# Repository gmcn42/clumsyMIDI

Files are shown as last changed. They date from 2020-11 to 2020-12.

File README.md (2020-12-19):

# clumsyMIDI
A Raspberry Pi expansion board containing a MIDI interface, DAC, and OLED display requiring only through-hole soldering skills. This is primarily intended as an all-in-one hardware solution for the [mt32-pi Roland MT-32 emulator](https://github.com/dwhinham/mt32-pi) but all features are usable with Raspberry Pi OS, too.

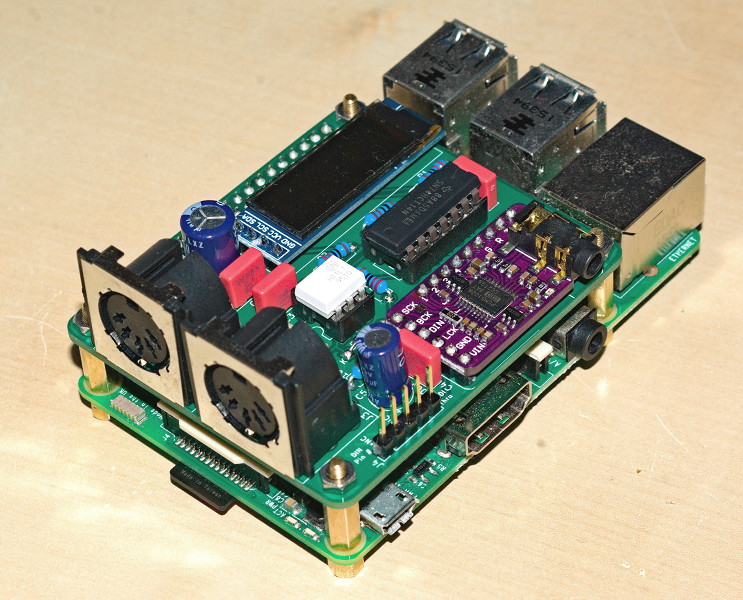
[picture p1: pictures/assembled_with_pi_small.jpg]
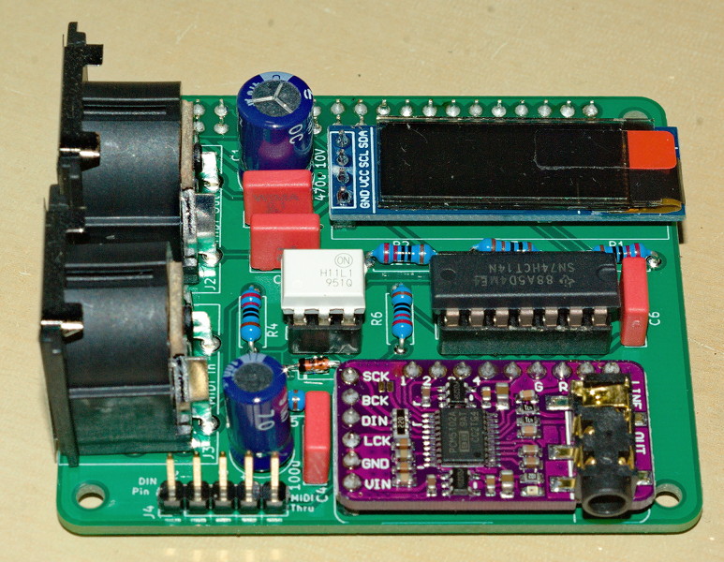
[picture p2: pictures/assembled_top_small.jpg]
[](https://github.com/gmcn42/clumsyMIDI/raw/main/pictures/assembled_with_pi.jpg) [](https://github.com/gmcn42/clumsyMIDI/raw/main/pictures/assembled_top.jpg)

## Table of contents

<!-- toc -->
- [Features](#features)
- [Schematic and BOM](#schematic-and-bom)
- [How to get the PCB](#how-to-get-the-pcb)
  * [PCB Specs](#pcb-specs)
- [Assembly](#assembly)
  * [An ⚠IMPORTANT⚠ note on the DAC board solder bridges](#an-important-note-on-the-dac-board-solder-bridges)
  * [Rewiring MIDI Thru to Out](#rewiring-midi-thru-to-out)
  * [Mechanical Parts](#mechanical-parts)
  * [A General Note](#a-general-note)
- [Software Config](#software-config)
  * [mt32-pi](#mt32-pi)
  * [Raspberry Pi OS](#raspberry-pi-os)

<!-- tocstop -->

## Features
* TI PCM5102 I2S HiFi DAC (using the ubiquitous GY-PCM5102 carrier board)
* GPIO MIDI interface with in, out, and thru
* 0.91" OLED display
* large-ish 5V bypass capacitor which may help with slightly weak power supplies
* works with [mt32-pi](https://github.com/dwhinham/mt32-pi) and Raspberry Pi OS
* no SMT soldering required, so it should be suitable for clumsy DIYers like me ;)

## Schematic and BOM
Schematic and BOM are available in the [`pdf/` subfolder](https://github.com/gmcn42/clumsyMIDI/tree/main/pdf).

## How to get the PCB
You can get a zip file with the Gerber files from the [releases page](https://github.com/gmcn42/clumsyMIDI/releases/) and let your favorite board house build the PCB. Alternatively, you can also order directly from PCBWAY via [this link](https://www.pcbway.com/project/shareproject/clumsyMIDI___Raspberry_Pi_expansion_board.html) for convenience. Full disclosure: If you use the link, PCBWAY will donate 10% of the PCB price to me. I want to make clear that the PCB design is completely free and you are in no way obligated or even encouraged to use that link.

In case you want to make changes to the PCB before ordering somewhere, you can use [KiCAD](https://kicad.org/) and import the project.

***⚠IMPORTANT NOTE:⚠*** Before soldering down the DAC board please make *sure* you check the [assembly instructions below about the DAC's solder bridges](#an-important-note-on-the-dac-board-solder-bridges). Their factory configuration appears to be varying from supplier to supplier and you may need to change them.

### PCB Specs
* PCB size (height * width): 56mm * 65mm
* Layers: 2
* Minimum drill size: 0.6mm
* Minimum track size: 0.25mm (=9.84mil)
* Minimum track clearance/spacing: 0.25mm (=9.84mil)
* Surface finish: by preference (the pictured boards are lead-free HASL but pretty much anything will do)

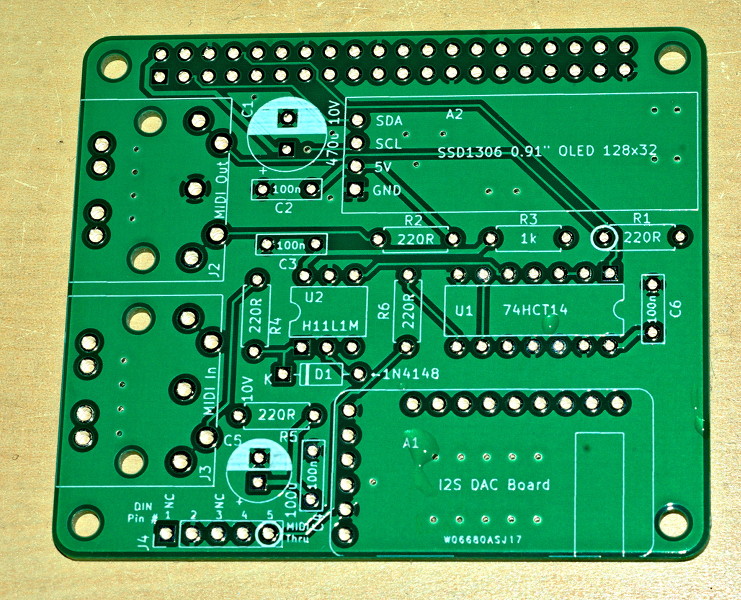
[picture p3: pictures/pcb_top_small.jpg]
[](https://github.com/gmcn42/clumsyMIDI/raw/main/pictures/pcb_top.jpg)
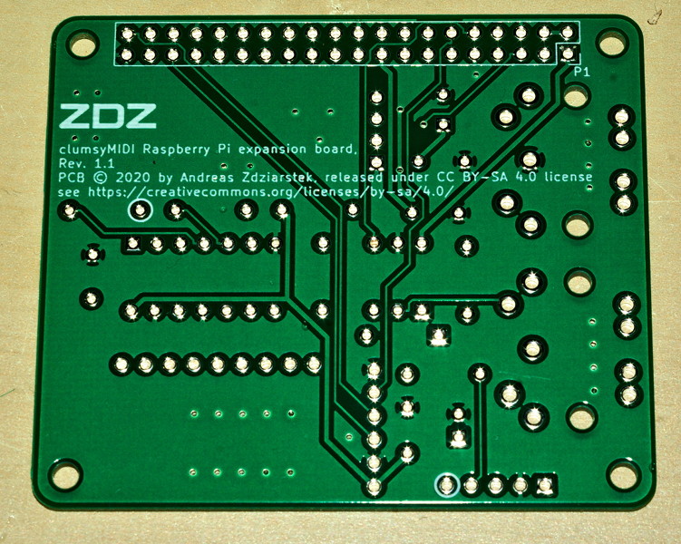
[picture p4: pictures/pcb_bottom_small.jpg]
[](https://github.com/gmcn42/clumsyMIDI/raw/main/pictures/pcb_bottom.jpg)

## Assembly
As all components are through-hole, you should get by with basic soldering skills. It is usually the best idea to start with the flattest components and work your way up. The 40-Pin GPIO socket should be soldered on last, also remember that it goes on the *bottom* :).

As shown in the BOM, I recommend socketing U1 and U2 as they are the most likely casualties if defective MIDI devices are connected for some reason. Be mindful of the ICs' orientation. The notch of the 74HCT14 should be where the notch is on the silkscreen. Likewise, the H11L1's dot (marking for Pin 1) should also face the in the direction of the notch on the silkscreen. If inserted correctly, U1 and U2 will "face outward and away from each other".

It is possible to leave out some components, e.g. if you only need MIDI-In. Consult [the schematic](https://github.com/gmcn42/clumsyMIDI/blob/main/pdf/clumsyMIDI-schematic.pdf) for details.

As I happily noticed people are actually really starting to build these things, I have opened the [discussions page](https://github.com/gmcn42/clumsyMIDI/discussions) of this project. If you have questions about anything related to the board and its assembly, feel free to open a topic!

### An ⚠IMPORTANT⚠ note on the DAC board solder bridges
Before soldering on the DAC board please double-check that the solder bridges on the bottom of your GY-PCM5102 are configured as in the following picture:

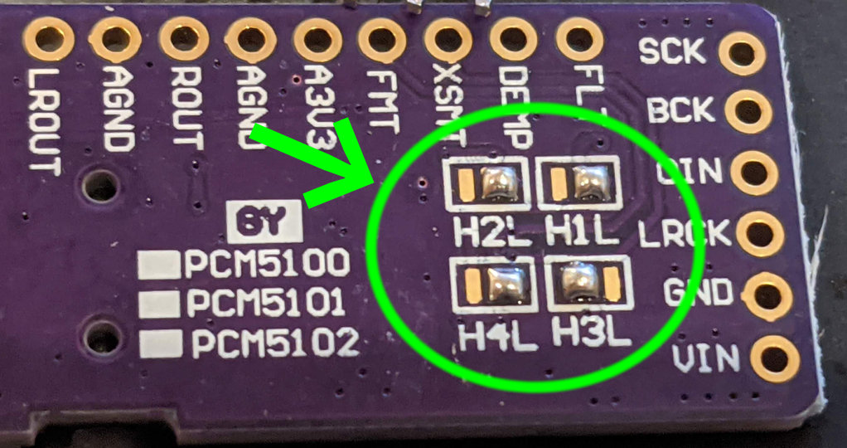
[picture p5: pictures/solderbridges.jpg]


So: 1, 2, and 4 to L and 3 to H. This should be the standard factory-set config but at least one builder encountered a board with an unconnected bridge resulting in the DAC being permanently muted. If you have a multimeter you might also want to check good connection from the board's pins to rule out bad solder joints. FLT, FMT, and DEMP should have almost 0Ω to GND while XSMT should have almost 0Ω to pin 20 (top right) of the DAC chip itself.

If yours are un- or wrongly set, you'll have to resolder them.

### Rewiring MIDI Thru to Out
In standard configuration, the MIDI Thru output is available on a 5-pin header due to space constraints. If you do not need MIDI Out but want a MIDI Thru, it is possible to route the Thru signal to the MIDI-Out socket instead of the pin header. In that case, leave J4, R1, and R5 unpopulated and solder a wire between the footprint pads of J4 and R1 marked with a circle on the silkscreen, as shown in these two pictures (click for larger version):

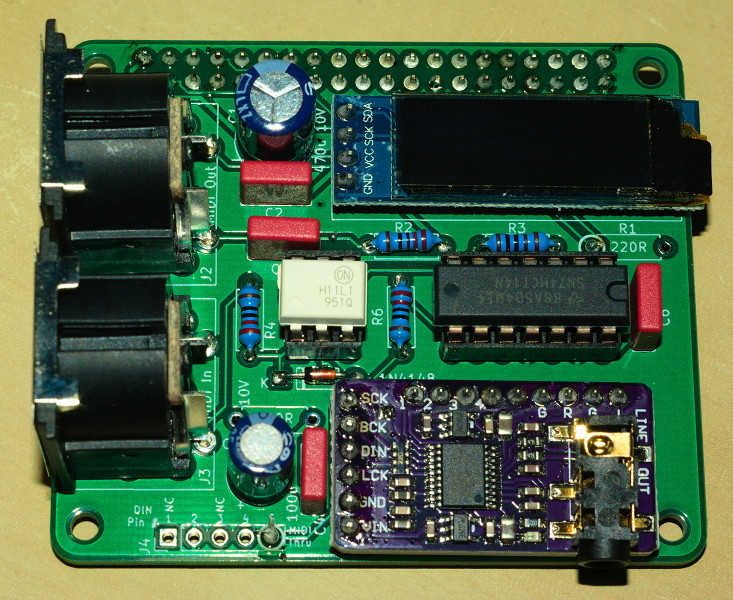
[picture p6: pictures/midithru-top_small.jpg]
[](https://github.com/gmcn42/clumsyMIDI/raw/main/pictures/midithru-top.jpg)
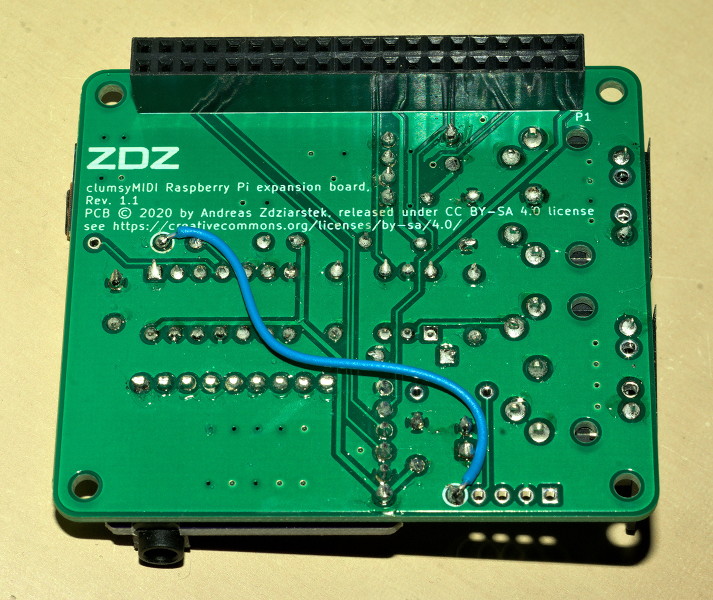
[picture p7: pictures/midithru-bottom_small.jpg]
[](https://github.com/gmcn42/clumsyMIDI/raw/main/pictures/midithru-bottom.jpg)

### Mechanical Parts
Be sure to use some kind of standoffs or similar when connecting clumsyMIDI to the PI. Without them, the board may sit lopsided and come in contact with the HDMI port, potentially causing a short circuit. Apart from that, it's more mechanically stable and simply looks nicer :). The BOM contains the brass standoffs I am using in the pictures.

### A General Note
Use caution and common sense while working with electronics, especially while soldering stuff. As stated in the license, I am offering this PCB design as-is incuding any and all defects it may have and will not be held liable for any harm that comes to you or others as a result of using/building/looking at it.

## Software Config
### mt32-pi
Follow the setup instructions on their site and then set the following options in `mt32-pi.cfg`:
```
usb = off
output_device = i2s
type = ssd1306_i2c
```
The option `gpio_thru` will also work with the MIDI Out port on clumsyMIDI, so use at your preference.

### Raspberry Pi OS
You need to add the following to `/boot/config.txt` to get GPIO MIDI, I2S DAC, and I2C support
```
enable_uart=1
dtoverlay=pi3-miniuart-bt
dtoverlay=midi-uart0

dtparam=i2s=on
dtoverlay=hifiberry-dac

dtparam=i2c_arm=on,i2c_arm_baudrate=400000
```
Also you need to comment out or remove the line `dtparam=audio=on`

Additionally for I2C support, add the following line to `/etc/modules`:
```
i2c-dev
```

To get regular ALSA MIDI support you need to bridge `/dev/ttyAMA0` and an ALSA MIDI port. You can do this with [`ttymidi`](https://github.com/cjbarnes18/ttymidi).
Once you have it compiled and installed, run the following in a terminal:
```
sudo ttymidi -s /dev/ttyAMA0 -b 38400
```
If you are asking yourself why it needs to be set to 38400 Baud: The line `dtoverlay=midi-uart0` causes the Pi's UART base clock to be slightly lowered, so that 38400 (a common RS232 baud rate) effectively becomes 31250 Baud which is MIDI-compatible.

Now you when run `aconnect -l` in another terminal, you should see a new MIDI client. Something similar to:
```
client 128: 'ttymidi' [type=user,pid=920]
    0 'MIDI out     '
    1 'MIDI in      '
```
Somewhat confusingly, the out/in naming is reversed because it is from the perspective of `ttymidi`. That means 'MIDI in' is what it receives from another application and then forwards to the UART. So if you want to play something on a synth connected to the clumsyMIDI's output, the correct command will be
```
aplaymidi -p 128:1 somefile.mid
```

The I2C display is supported by the [Adafruit SSD1306 Python library](https://github.com/adafruit/Adafruit_Python_SSD1306.git), among others.

Have fun!

clumsyMIDI ©2020 by Andreas Zdziarstek.<br>This work is licensed under a [Creative Commons Attribution-ShareAlike 4.0 International License](https://creativecommons.org/licenses/by-sa/4.0/).<br>

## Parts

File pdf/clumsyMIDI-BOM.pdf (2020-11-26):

### clumsyMIDI – Bill of Materials

Total Component Count: 23

Reference | Qnty Value | Footprint | Description
A1, | 1 | GY-PCM5102 | Custom | GY-PCM5102 DAC board (cheaply available on eBay/AliExpress)
A2, | 1 | SSD1306 Header | Custom
C1, | 1 | 470u 10V | Electrolytic capacitor, preferably low ESR
C2, C3, C4, C6, | 4 | 100n | Unpolarized bypass capacitors, use either X7R or film (e.g. WIMA MKS2)
C5, | 1 | 100u | | Electrolytic capacitor
D1, | 1 | 1N4148 | DO-35 | Fast Switching Diode
J2, J3, | 2 | MIDI In & Out Jacks | DIN 5 Pin Jack (Universal) | 5-pin DIN socket, (hopefully) with universal footprint for most types
J4, | 1 | MIDI Thru Jack | Pin Header 1x05 2.54mm Pitch | 5-pin DIN connector (Pin Header only)
P1, | 1 | Conn_02x20_Odd_Even | Raspberry PI GPIO Socket
R1, R2, R4, R5, R6, | 5 | 220Ω | | Resistor
R3, | 1 | 1kΩ | Resistor
U1, | 1 | 74HCT14 | DIP-14 W7.62mm | Hex inverter schmitt trigger
U2, | 1 | H11L1M | DIP-6 W7.62mm
S1, | 1 | DIP-14 socket | DIP-14 W7.62mm | Optional socket for U1
S2, | 1 | DIP-6 socket | DIP-6 W7.62mm | Optional socket for U2
Mechanical Parts: | 4x M2.5 nut, 4x M2.5x11+6 standoff, 4x M2.5x5+6 standoff

0.91” SSD1306 OLED board, use 5V compatible boards with 3.3V regulator (usually marked Q1 or U1) on the back of the board (cheaply available on eBay/AliExpress)
THT Electrolytic Cap Radial D8.0mm, 3.5mm pitch
THT Unpolarized Capacitor, Rectangular 7.0mm x 2.0mm, 5.00mm pitch
THT Electrolytic Cap Radial D6.3mm, 2.5mm pitch

Generic connector, double row, 02x20, odd/even pin numbering scheme (row 1 odd numbers, row 2 even numbers)
THT Resistor DIN0207
(L6.3mm x D2.5mm, 7.62mm
pitch)
THT Resistor DIN0207
(L6.3mm x D2.5mm, 7.62mm
pitch)

Schmitt Trigger Output Optocoupler, High Speed, DIP-6, 1.6mA turn on threshold

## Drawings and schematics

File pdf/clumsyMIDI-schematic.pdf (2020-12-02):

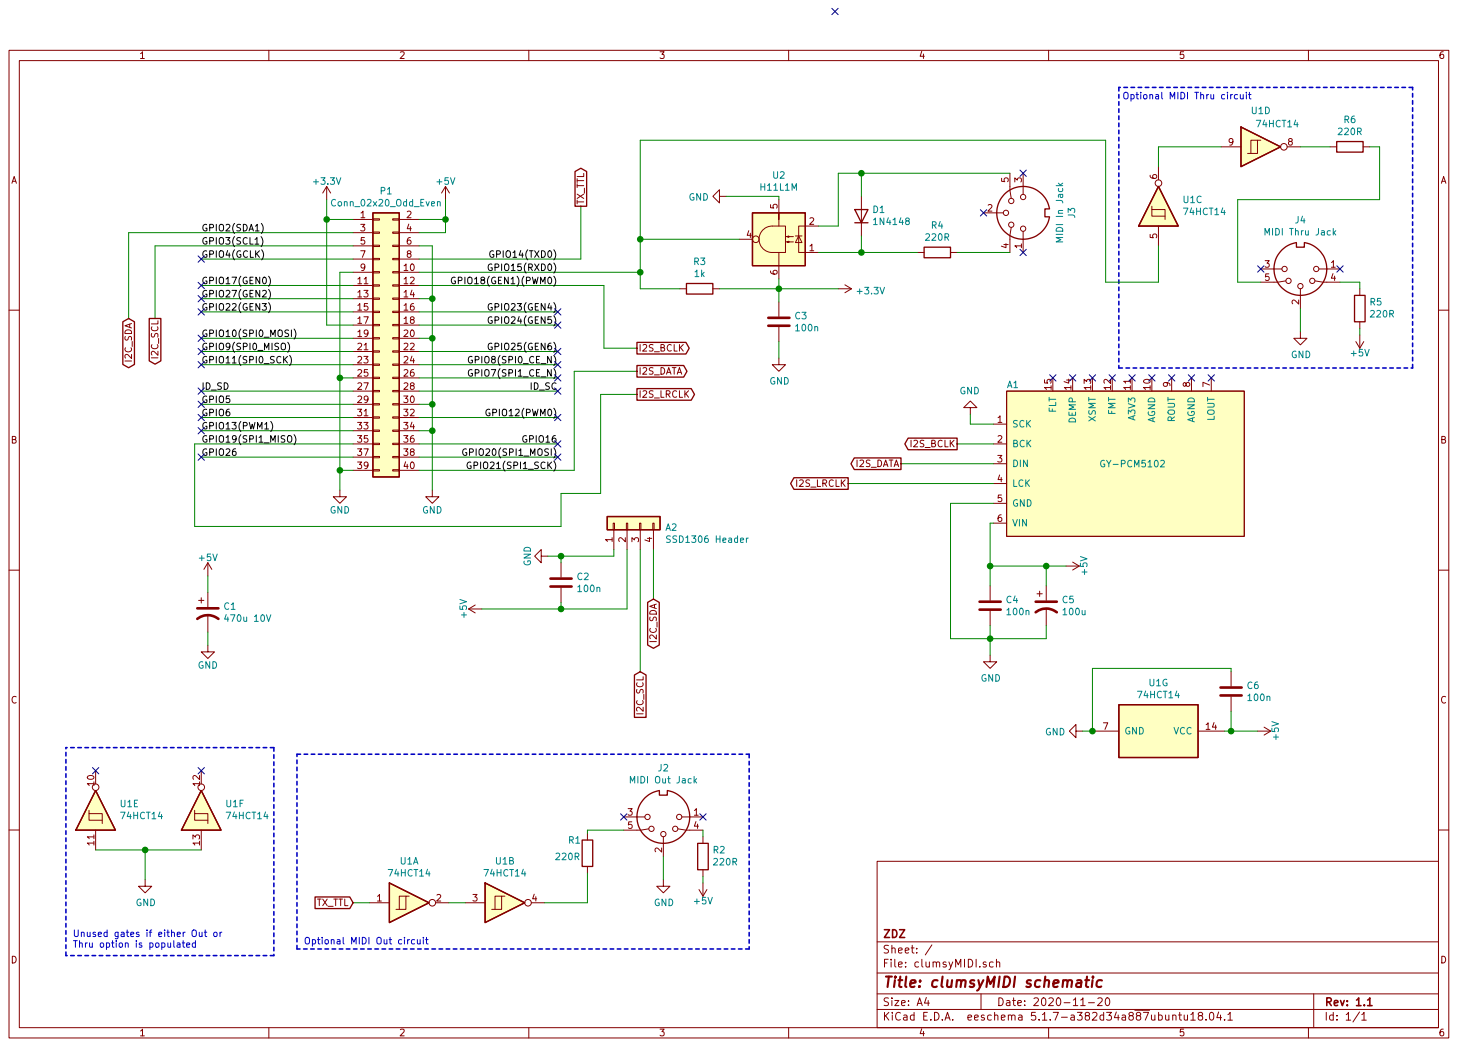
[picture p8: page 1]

Optional MIDI Thru circuit

GPIO3(SCL1) | 5 | | 6

17 | 18 | GPIO24(GEN5)
19 | 20 | GPIO25(GEN6)
21 | 22
23 | 24
25 | 26
27 | 28

31 | | 32
33 | | 34
35 | | 36
37 | | 38
39 | | 40 | GPIO21(SPI1_SCK)

Optional MIDI Out circuit Unused gates if either Out or
Thru option is populated

File: clumsyMIDI.sch Sheet: / ZDZ

Id: 1/1 Title: clumsyMIDI schematic

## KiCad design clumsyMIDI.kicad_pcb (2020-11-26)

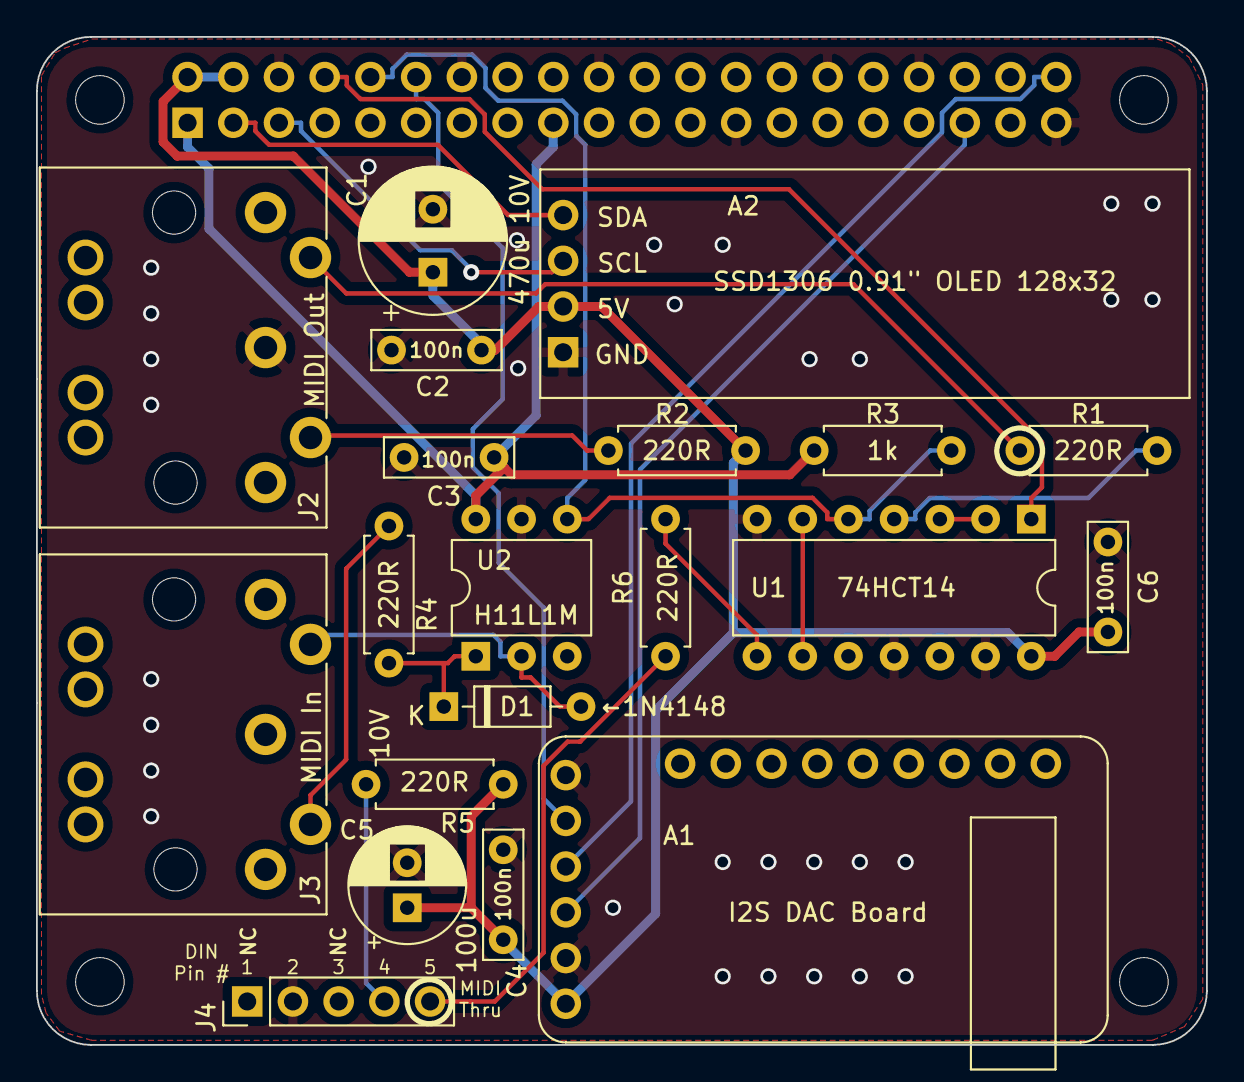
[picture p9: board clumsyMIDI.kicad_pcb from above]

Board: 2 copper layers, 65.0 x 56.0 mm, 25 parts (1 on the bottom side), 21 nets.

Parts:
A1: GY-PCM5102
A2: SSD1306 Header; SSD1306_128_32
C1: 470u 10V; CP_Radial_D8.0mm_P3.50mm
C2, C3, C4, C6: 100n; C_Rect_L7.0mm_W2.0mm_P5.00mm
C5: 100u; CP_Radial_D6.3mm_P2.50mm
D1: 1N4148; D_DO-35_SOD27_P7.62mm_Horizontal
J2: MIDI Out Jack; MultiDIN5
J3: MIDI In Jack; MultiDIN5
J4: MIDI Thru Jack; PinHeader_1x05_P2.54mm_Vertical
MK1, MK2, MK3, MK4: M2.5; MountingHole_2.7mm_M2.5
P1: Conn_02x20_Odd_Even; PinSocket_2x20_P2.54mm_Vertical
R1, R2, R4, R5, R6: 220R; R_Axial_DIN0207_L6.3mm_D2.5mm_P7.62mm_Horizontal
R3: 1k; R_Axial_DIN0207_L6.3mm_D2.5mm_P7.62mm_Horizontal
U1: 74HCT14; DIP-14_W7.62mm
U2: H11L1M; DIP-6_W7.62mm

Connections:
+3V3: C3.1, P1.1, P1.17, R3.1, U2.6
+5V: A1.6, A2.2, C1.1, C2.2, C4.1, C5.1, C6.2, P1.2, P1.4, R2.1, R5.1, U1.14
/GPIO15(RXD0): P1.10, R3.2, U1.5, U2.4
GND: A1.1, A1.5, A2.1, C1.2, C2.1, C3.2, C4.2, C5.2, C6.1, J2.2, J4.2, P1.6, P1.9, P1.14, P1.20, P1.25, P1.30, P1.34, P1.39, U1.7, U1.11, U1.13, U2.5
I2C_SCL: A2.3, P1.5
I2C_SDA: A2.4, P1.3
I2S_BCLK: A1.2, P1.12
I2S_DATA: A1.3, P1.40
I2S_LRCLK: A1.4, P1.35
unnamed: D1.1, R4.2, U2.1
unnamed: D1.2, J3.5, U2.2
unnamed: J2.4, R2.2
unnamed: J2.5, R1.1
unnamed: J3.4, R4.1
unnamed: J4.4, R5.2
unnamed: J4.5, R6.1
unnamed: R1.2, U1.4
unnamed: R6.2, U1.8
unnamed: U1.2, U1.3
unnamed: U1.6, U1.9
TX_TTL: P1.8, U1.1

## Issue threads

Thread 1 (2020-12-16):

No audio

fierodoug, 2020-12-16:
I am having a odd issue.
Everything is working but I am getting no audio out of the 3.5mm jack on the DAC, unless I touch the top row of header pins on the DAC with my finger. I almost dont have to touch it, just put my finger near it. Remove my finger and the audio goes away.
Any suggestions?
Thanx
Doug

fierodoug, 2020-12-17:
touching a 10k ohm resistor from VIN to 3 on the DAC board gets audio working. Not sure if that is a good fix though

gmcn42, 2020-12-17:
Hi Doug,

thanks for reporting!

Pin 3 is indeed the PCM5102's soft-mute (GND=mute, 3V3=sound on). All of the DAC boards I have here seem to have some kind of Pull-Up resistor. Pin 3 shows 3.3V when not connected and power is applied, yours will probably show 0V (can you check with multimeter.

As for the fix: I recommend you DO NOT connect to VIN as this is the 5V input which goes to the board's 3.3V regulator. 5V might damage the DAC chip over time even through a 10K resistor. Instead make a connection between pin 3 and pin 5 of the DAC board. Pin 5 is the board's internal 3.3V supply. You can just add a piece of bent wire clipping below the board, a resistor should not be needed.

Please let me know if that helps. If yes, I'll add it to the instructions for now and make a Rev. 1.2 with the 3-5 connection.

gmcn42, 2020-12-17:
I also just remembered, the DAC board has solder bridges for pull-up or down on the bottom side (my boards are all soldered on so I couldn't see them just now :D). The one marked "3" should be in the "H" position then the board should -- theoretically -- unmute without external connections.

The fix with the 3-5 connection should still be fine but resoldering the bridges on the DAC board might be the cleaner solution if you can do it.

gmcn42, 2020-12-17:
Okay, 3rd post, sorry about that. I just checked another board I found lying around. It is correctly solder-bridged as in the picture above. But the thing I noticed: The solder bridges seem to be a hard connection (0Ohms) to either GND or 3V3.

If yours can be overridden (and with a 10K resistor at that) this makes me think there is either no solder bridge at all or the solder joint is broken.

Another thing this would mean: If my hard-connected DAC board would be bridged 3-L, it would be permanently muted without possibility to externally unmute (and also risking a short-circuit) which is a design decision I do not fully understand right now...

fierodoug, 2020-12-18:
My board is soldered in so I could not check the jumpers. Pin 3 has 0 volts
using a jumper between pins 3 and 5 did the trick, working great now
Thanx

gmcn42, 2020-12-18:
Okay, great! So the "3" bridge on your board indeed did not have a connection. Would be interesting to know how many this affects.
Anyone who reads this and has a board which deviates from the picture, let me know!

If you have any other weirdness occuring, you _might_ need to tie pins 1,2,3 to GND. I am thinking that if one bridge is unsoldered, others might be, too. But you should check the connections with a multimeter before (see https://github.com/dwhinham/mt32-pi/discussions/46) to not short-circuit anything.

**Here is an important note for everyone:** This works for @fierodoug because the solder bridge on his DAC did not have a connection to either "H" or "L" for some reason. If yours is connected to "L" and you apply the 3-5 fix, you'll effectively short the 3.3V regulator and probably fry your board. The reason is that the bridges are direct (0Ω) connections and not via a resistor.
In the above case a direct "L" connection could be effectively ruled out due to a 10K resistor being able to pull the pin high which would not be possible with a low-resistance connection acting against it.

This is why I have decided to leave the PCB as-is and add a note to the assembly instructions to inspect the DAC's solder-bridges before soldering it down (see also: https://raspberrypi.stackexchange.com/a/94951). It is the most simple and definitely the safest option.

Thanks for bringing this to my attention!

gmcn42, 2020-12-18:
Have added the README notes in https://github.com/gmcn42/clumsyMIDI/commit/45f0cd28b3406055cf1820e843b63580c1329eb9

dwhinham, 2021-01-05:
A user encountered the same problem when using this module via wire connection, so I've created a new wiki page over at mt32-pi too to address this: https://github.com/dwhinham/mt32-pi/wiki/GY-PCM5102-DAC-module

Thanks for figuring this out! 🙂

Joshfindit, 2022-10-05:
Adding for anyone in future: the board I got had small pins across the pads instead of a solder blob.

It's conceivable that they could get knocked off and cause this issue

Closed 2020-12-18.

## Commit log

2020-11-26 Added PDF BOM and schematic
    [clumsyMIDI.sch]
2020-11-26 Add mechanical parts to BOM
2020-11-26 BOM formatting.
2020-11-26 Update README.md
    fix PCBWAY link
2020-11-29 Add PCB specs for board houses to README
2020-12-02 fixed the MIDI connector symbols in the schematic (no PCB change)
    [clumsyMIDI.sch]
2020-12-07 Clarify MIDI/ttymidi setup on Raspberry Pi OS
    Clarify MIDI/ttymidi setup on Raspberry Pi OS, also added the i2c-dev kernel module thing for the display which I forgot before
2020-12-18 Add picture of solder bridges on DAC board.
2020-12-18 Add instructions about DAC solder bridges
2020-12-19 Make DAC board note more visible

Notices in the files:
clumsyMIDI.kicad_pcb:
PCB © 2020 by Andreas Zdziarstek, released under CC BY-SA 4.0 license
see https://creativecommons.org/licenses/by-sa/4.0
